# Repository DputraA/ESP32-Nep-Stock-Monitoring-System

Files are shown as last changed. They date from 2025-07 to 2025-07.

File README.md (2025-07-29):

# ESP32 Nepel Stock Monitoring System

Sistem monitoring persediaan nepel berbasis ESP32, multiplexer (MUX), dan web server lokal, dengan fitur pengiriman data ke Google Sheets dan tampilan real-time status melalui halaman web. Sistem ini digunakan untuk mendeteksi apakah stok nepel tersedia (`ready`) atau habis (`runout`), dan mencatat log perubahan status serta uptime WiFi ESP32.

---

## Fitur Utama

- Monitoring hingga 4 channel sensor digital (bisa diperluas)
- Deteksi perubahan status sensor secara otomatis
- Pengiriman data ke Google Spreadsheet via WebScript
- Webserver lokal dengan tampilan status dan log
- Fitur uptime monitoring (timer berjalan jika WiFi aktif)
- Auto-refresh dashboard jika ada perubahan
- Log maksimal 10 perubahan terakhir ditampilkan di halaman web
- Auto-reconnect jika WiFi terputus

---

## Struktur Proyek

File utama:
- `main.ino`= file kode utama ESP32
- `README.md`= dokumentasi ini
- 'Appscript for Spreadsheet.json' = Appscript penghubung ke spreadsheet
- 'Dashboard monitoring stock nepel.html' = Auto redirect ke halaman webserver
---

## Tampilan Webserver

Dashboard lokal menampilkan:
- Status semua channel (warna hijau = ready, merah = runout)
- Timestamp update terakhir setiap channel
- Log perubahan terakhir
- Uptime dari koneksi WiFi

---

##  Cara Upload dan Jalankan

1. Buka file `.ino` dengan Arduino IDE
2. Pastikan library berikut sudah tersedia:
   - `WiFi.h`
   - `WebServer.h`
   - `HTTPClient.h`
   - `ArduinoJson.h`
   - `time.h`
3. Atur:
   - `ssid` dan `password` sesuai WiFi lokal
   - `scriptURL` sesuai link Google Apps Script Anda
4. Upload ke ESP32
5. Buka file 'Dashboard monitoring stock nepel.html' di browser

---

## Menambah Channel Sensor

Secara default, sistem membaca 4 channel (`totalChannels = 4`). Untuk menambah jumlah channel:

1. Ubah variabel `totalChannels`:
  	 ```cpp
  	 const int totalChannels = 8;
2. Update array namaNepel[] agar mencakup semua channel baru:

 	  ```cpp
	const char* namaNepel[totalChannels] = {
	"Nepel 12-12", "Nepel 12-10", "Nepel 10-10", "Nepel Single 10",
	"Nepel Extra 1", "Nepel Extra 2", "Nepel Extra 3", "Nepel Extra 4"
	};
3. (Opsional) Aktifkan multiplexer kedua/ketiga jika total channel melebihi 8 atau 16:

	```cpp
	digitalWrite(muxEN1, LOW);  // Channel 0–7
	digitalWrite(muxEN2, LOW);  // Channel 8–15 (MUX 2)
	digitalWrite(muxEN3, LOW);  // Channel 16–23 (MUX 3)

## Mengganti Nama Channel
1. Edit isi array namaNepel[] sesuai urutan channel:

	```cpp
	const char* namaNepel[totalChannels] = {
	  "Nepel A", "Nepel B", "Nepel C", "Nepel D"
	};

2. Nama ini akan digunakan untuk:

- Label log di spreadsheet

- Tampilan web dashboard

- JSON yang dikirim ke Google Sheets

## Membuka Webserver Menggunakan redirect `.html`

Agar lebih mudah mengakses IP lokal ESP32 tanpa mengetik alamat IP manual, gunakan file Redirect `Dashboard monitoring stock nepel.html`.

## Catatan Tambahan
Tempat penyimpanan fisik saat ini hanya mampu menampung 4 jenis material nepel dan menggunakan impraboard.
Disarankan untuk mengganti tempat penyimpanan ke bahan stainless steel agar lebih kuat, awet, dan cocok digunakan di lingkungan pabrik.
Pastikan power supply memberikan tegangan 5V stabil ke ESP32, dan 24V untuk sensor serta pilot lamp.

![Dashboard](https://github.com/user-attachments/assets/8dd31693-6f9d-41be-ad02-e86e2364a81c)

## Lisensi
Proyek ini bersifat open-source dan bebas digunakan untuk edukasi dan pengembangan lebih lanjut.

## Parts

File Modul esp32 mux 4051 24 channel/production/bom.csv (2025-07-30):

Designator | Footprint | Quantity | Value | LCSC Part #
C1, C3 | CP_Elec_8x10 | 2 | 220uF
C2, C4 | 1206 | 2 | 100nF
D1, D2 | D_SMA_Handsoldering | 2 | SS14
D3 | 1206 | 1 | LED
J1, J2 | PinHeader_1x02_P2.54mm_Vertical | 2 | Conn_01x02_Socket
J10, J11, J12, J13, J14, J15, J16, J17, J18, J19, J20, J21, J22, J23, J24, J25, J26, J27, J4, J5, J6, J7, J8, J9 | JST_XH_B3B-XH-A_1x03_P2.50mm_Vertical | 24 | Conn_01x03_Pin
J3 | KF7.62_2P | 1 | Screw_Terminal_01x02
L1 | L_12x12mm_H8mm | 1 | 68uH
M1, M2, M3 | SOIC-16W_5.3x10.2mm_P1.27mm | 3 | 74HC4051
R1, R10, R11, R12, R13, R14, R15, R16, R17, R18, R19, R2, R20, R21, R22, R23, R24, R25, R26, R27, R28, R3, R5, R6, R7, R8, R9 | 1206 | 27 | R
R4 | 1206 | 1 | 1K
U1 | MODULE_ESP32-DEVKITC | 1 | ESP32-DEVKITC-v4
U10, U11, U12, U13, U14, U15, U16, U17, U18, U19, U20, U21, U22, U23, U24, U25, U26, U3, U4, U5, U6, U7, U8, U9 | DIP-4_W7.62mm_SMDSocket_SmallPads | 24 | PC817
U2 | TO-263-5_TabPin3 | 1 | LM2596S-5

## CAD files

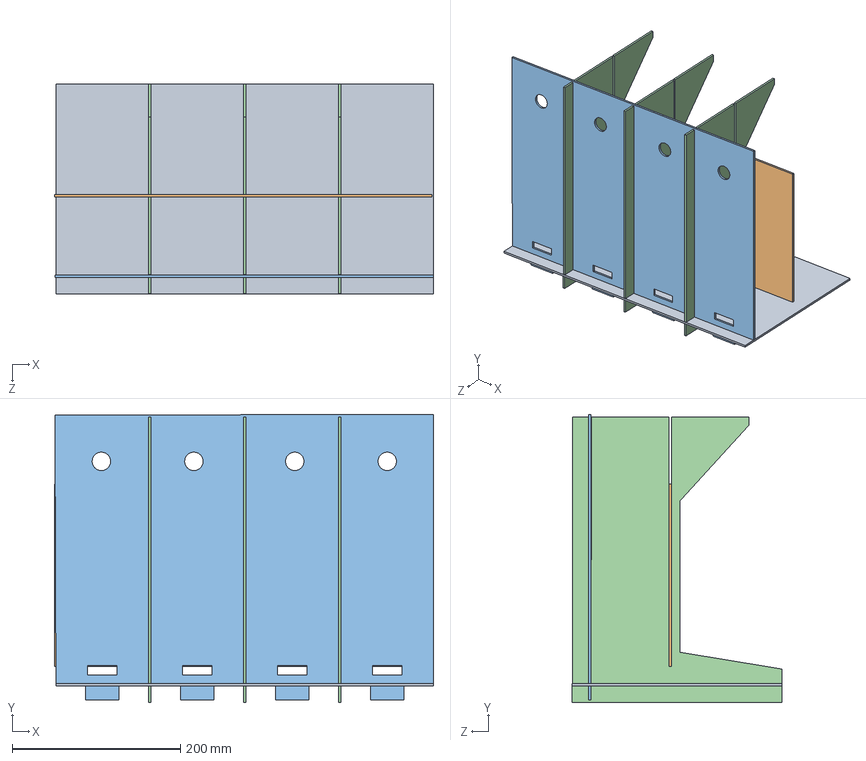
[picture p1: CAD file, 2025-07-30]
dispenser nepel/assy.SLDASM
450.7 x 343.0 x 250.0 mm
bawah
depan
dinding belakang
dinding pinggir x 3

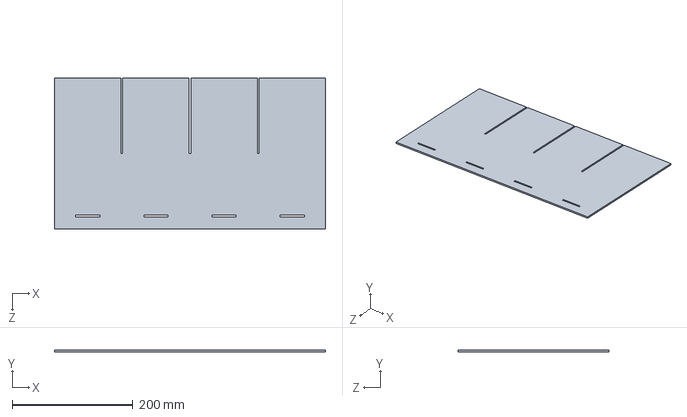
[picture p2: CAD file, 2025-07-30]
dispenser nepel/bawah.SLDPRT
449.0 x 3.00 x 250.0 mm

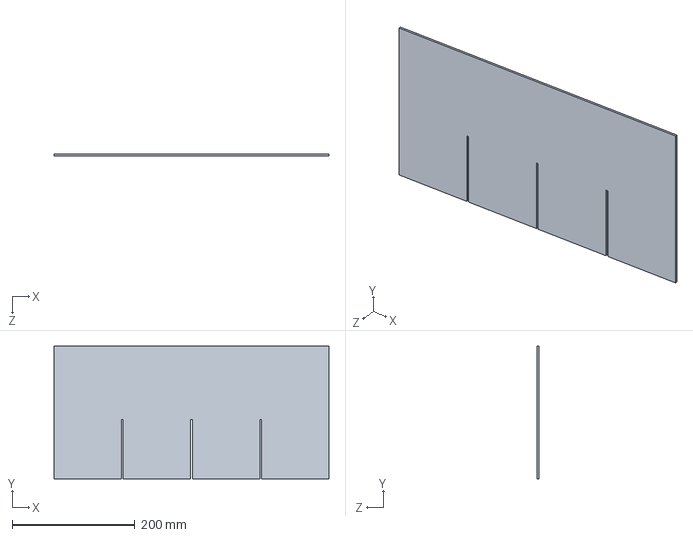
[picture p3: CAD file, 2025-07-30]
dispenser nepel/depan.SLDPRT
449.0 x 217.0 x 3.00 mm

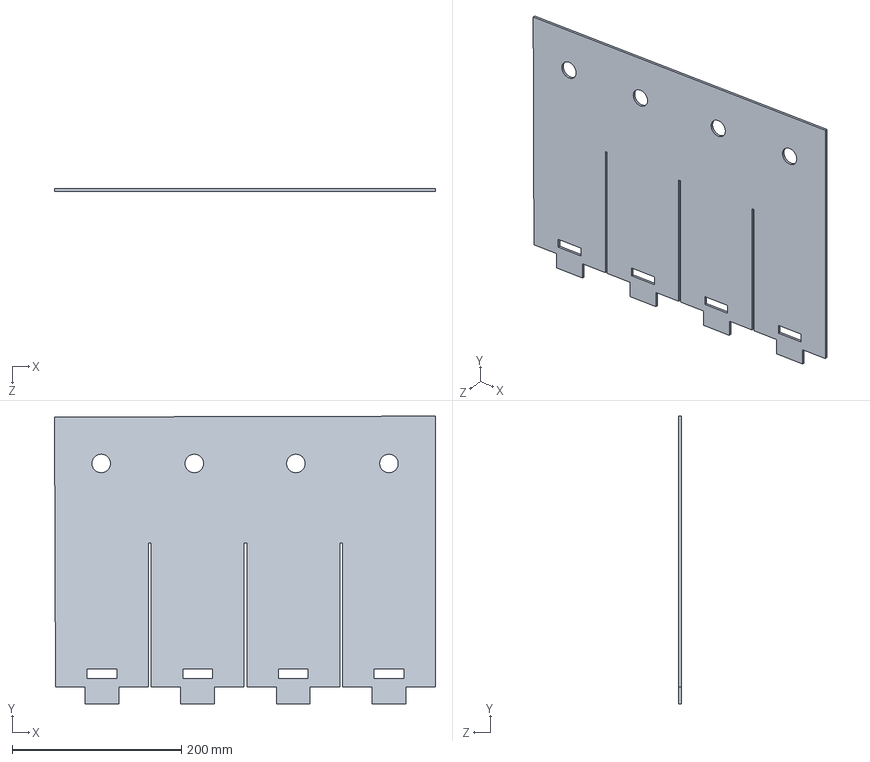
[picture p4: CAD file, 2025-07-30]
dispenser nepel/dinding belakang.SLDPRT
450.2 x 340.0 x 3.00 mm

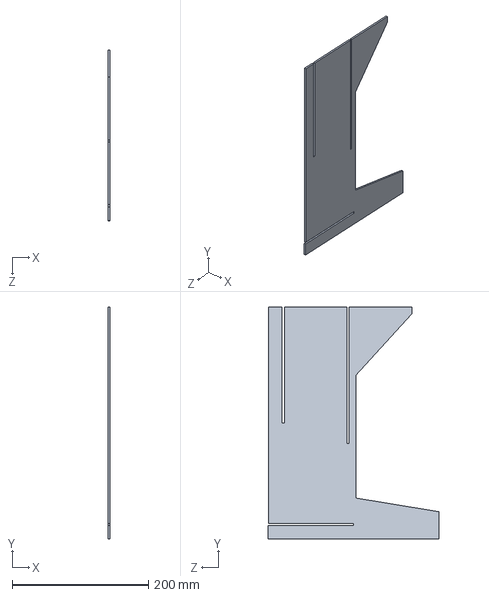
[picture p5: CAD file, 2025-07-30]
dispenser nepel/dinding pinggir.SLDPRT
3.00 x 340.0 x 250.0 mm

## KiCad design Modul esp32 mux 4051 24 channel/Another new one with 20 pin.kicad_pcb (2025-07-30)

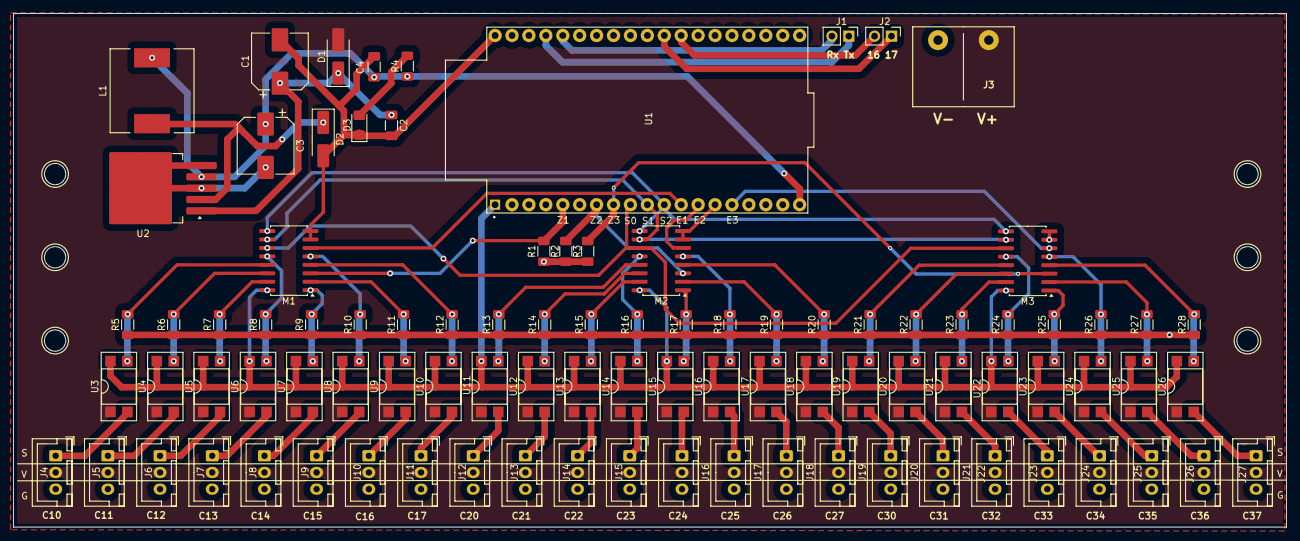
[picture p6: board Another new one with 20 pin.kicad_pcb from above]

Board: 2 copper layers, 191.1 x 77.1 mm, 92 parts (0 on the bottom side), 68 nets.

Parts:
C1, C3: 220uF; CP_Elec_8x10
C2, C4: 100nF; C_1206_3216Metric_Pad1.33x1.80mm_HandSolder
D1, D2: SS14; D_SMA_Handsoldering
D3: LED; LED_1206_3216Metric_Pad1.42x1.75mm_HandSolder
J1, J2: Conn_01x02_Socket; PinHeader_1x02_P2.54mm_Vertical
J3: Screw_Terminal_01x02; KF7.62_2P
J4, J5, J6, J7, J8, J9, J10, J11, J12, J13, J14, J15, J16, J17, J18, J19, J20, J21, J22, J23, J24, J25, J26, J27: Conn_01x03_Pin; JST_XH_B3B-XH-A_1x03_P2.50mm_Vertical
L1: 68uH; L_12x12mm_H8mm
M1, M2, M3: 74HC4051; SOIC-16W_5.3x10.2mm_P1.27mm
R1, R2, R3, R5, R6, R7, R8, R9, R10, R11, R12, R13, R14, R15, R16, R17, R18, R19, R20, R21, R22, R23, R24, R25, R26, R27, R28: R; R_1206_3216Metric_Pad1.30x1.75mm_HandSolder
R4: 1K; R_1206_3216Metric_Pad1.30x1.75mm_HandSolder
U1: ESP32-DEVKITC-v4; MODULE_ESP32-DEVKITC
U2: LM2596S-5; TO-263-5_TabPin3
U3, U4, U5, U6, U7, U8, U9, U10, U11, U12, U13, U14, U15, U16, U17, U18, U19, U20, U21, U22, U23, U24, U25, U26: PC817; DIP-4_W7.62mm_SMDSocket_SmallPads

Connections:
/Buck Converter 24 to 5/GND: C1.2, C2.2, C3.2, C4.2, D2.2 (A), D3.1 (K), J3.2, J4.3, J5.3, J6.3, J7.3, J8.3, J9.3, J10.3, J11.3, J12.3, J13.3, J14.3, J15.3, J16.3, J17.3, J18.3, J19.3, J20.3, J21.3, J22.3, J23.3, J24.3, J25.3, J26.3, J27.3, M1.7 (VEE), M1.8 (GND), M2.7 (VEE), M2.8 (GND), M3.7 (VEE), M3.8 (GND), R1.1, R2.1, R3.1, R5.1, R6.1, R7.1, R8.1, R9.1, R10.1, R11.1, R12.1, R13.1, R14.1, R15.1, R16.1, R17.1, R18.1, R19.1, R20.1, R21.1, R22.1, R23.1, R24.1, R25.1, R26.1, R27.1, R28.1, U1.14 (GND1), U1.32 (GND2), U1.38 (GND3), U2.3 (GND), U2.5 (~ON/OFF)
/Buck Converter 24 to 5/IN: D1.2 (A), J3.1, J4.2, J5.2, J6.2, J7.2, J8.2, J9.2, J10.2, J11.2, J12.2, J13.2, J14.2, J15.2, J16.2, J17.2, J18.2, J19.2, J20.2, J21.2, J22.2, J23.2, J24.2, J25.2, J26.2, J27.2, U3.1, U4.1, U5.1, U6.1, U7.1, U8.1, U9.1, U10.1, U11.1, U12.1, U13.1, U14.1, U15.1, U16.1, U17.1, U18.1, U19.1, U20.1, U21.1, U22.1, U23.1, U24.1, U25.1, U26.1
/Buck Converter 24 to 5/OUT (5V): C3.1, C4.1, L1.2, R4.1, U1.19 (EXT_5V), U2.4 (FB)
/Multiplexer/1: J4.1, U3.2
/Multiplexer/2: J5.1, U4.2
/Multiplexer/3: J6.1, U5.2
/Multiplexer/3.3v: M1.16 (VCC), M2.16 (VCC), M3.16 (VCC), U1.1 (3V3), U3.4, U4.4, U5.4, U6.4, U7.4, U8.4, U9.4, U10.4, U11.4, U12.4, U13.4, U14.4, U15.4, U16.4, U17.4, U18.4, U19.4, U20.4, U21.4, U22.4, U23.4, U24.4, U25.4, U26.4
/Multiplexer/4: J7.1, U6.2
/Multiplexer/5: J8.1, U7.2
/Multiplexer/6: J9.1, U8.2
/Multiplexer/7: J10.1, U9.2
/Multiplexer/8: J11.1, U10.2
/Multiplexer/9: J12.1, U11.2
/Multiplexer/10: J13.1, U12.2
/Multiplexer/11: J14.1, U13.2
/Multiplexer/12: J15.1, U14.2
/Multiplexer/13: J16.1, U15.2
/Multiplexer/14: J17.1, U16.2
/Multiplexer/15: J18.1, U17.2
/Multiplexer/16: J19.1, U18.2
/Multiplexer/17: J20.1, U19.2
/Multiplexer/18: J21.1, U20.2
/Multiplexer/19: J22.1, U21.2
/Multiplexer/20: J23.1, U22.2
/Multiplexer/21: J24.1, U23.2
/Multiplexer/22: J25.1, U24.2
/Multiplexer/23: J26.1, U25.2
/Multiplexer/24: J27.1, U26.2
/Multiplexer/En1: M1.6 (~E), U1.12 (IO14)
/Multiplexer/En2: M2.6 (~E), U1.13 (IO12)
/Multiplexer/En3: M3.6 (~E), U1.15 (IO13)
/Multiplexer/Out1: M1.3 (A), R1.2, U1.5 (IO34)
/Multiplexer/Out2: M2.3 (A), R2.2, U1.7 (IO32)
/Multiplexer/Out3: M3.3 (A), R3.2, U1.8 (IO33)
/Multiplexer/S0: M1.11 (S0), M2.11 (S0), M3.11 (S0), U1.9 (IO25)
/Multiplexer/S1: M1.10 (S1), M2.10 (S1), M3.10 (S1), U1.10 (IO26)
/Multiplexer/S2: M1.9 (S2), M2.9 (S2), M3.9 (S2), U1.11 (IO27)
unnamed: C1.1, C2.1, D1.1 (K), U2.1 (VIN)
unnamed: D2.1 (K), L1.1, U2.2 (OUT)
unnamed: D3.2 (A), R4.2
unnamed: J1.1, U1.35 (TXD0)
unnamed: J1.2, U1.34 (RXD0)
unnamed: J2.1, U1.28 (IO17)
unnamed: J2.2, U1.27 (IO16)
unnamed: M1.13 (A0), R5.2, U3.3
unnamed: M1.14 (A1), R6.2, U4.3
unnamed: M1.15 (A2), R7.2, U5.3
unnamed: M1.12 (A3), R8.2, U6.3
unnamed: M1.1 (A4), R9.2, U7.3
unnamed: M1.5 (A5), R10.2, U8.3
unnamed: M1.2 (A6), R11.2, U9.3
unnamed: M1.4 (A7), R12.2, U10.3
unnamed: M2.13 (A0), R13.2, U11.3
unnamed: M2.14 (A1), R14.2, U12.3
unnamed: M2.15 (A2), R15.2, U13.3
unnamed: M2.12 (A3), R16.2, U14.3
unnamed: M2.1 (A4), R17.2, U15.3
unnamed: M2.5 (A5), R18.2, U16.3
unnamed: M2.2 (A6), R19.2, U17.3
unnamed: M2.4 (A7), R20.2, U18.3
unnamed: M3.13 (A0), R21.2, U19.3
unnamed: M3.14 (A1), R22.2, U20.3
unnamed: M3.15 (A2), R23.2, U21.3
unnamed: M3.12 (A3), R24.2, U22.3
unnamed: M3.1 (A4), R25.2, U23.3
unnamed: M3.5 (A5), R26.2, U24.3
unnamed: M3.2 (A6), R27.2, U25.3
unnamed: M3.4 (A7), R28.2, U26.3

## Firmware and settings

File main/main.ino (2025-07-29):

#include <WiFi.h>
#include <WebServer.h>
#include <HTTPClient.h>
#include <ArduinoJson.h>
#include <time.h>

const char* ssid = "OJI"; //SSID WIFI yang digunakan
const char* password = "OnejectOJI88!"; //Passsword WIFI 
const char* scriptURL = "https://script.google.com/macros/s/AKfycbwVFrP5pP18-7c_LFjP_pqilvWdEAkJ4rLQRrOwwP4Hp_kgN0dRqTads4bqfNdSx2onWA/exec";

const int muxS0 = 18;
const int muxS1 = 26;
const int muxS2 = 27;

const int muxEN1 = 14;
const int muxEN2 = 12;
const int muxEN3 = 13;

const int muxSIG = 34;
const int totalChannels = 4; //Jumlah jenis nepel yang dideteksi

WebServer server(80);

int lastSensorValues[totalChannels];
unsigned long falseStartTimes[totalChannels];
unsigned long lastCheckTime = 0;
const unsigned long checkInterval = 1000;

const char* namaNepel[totalChannels] = {"Nepel 12-12", "Nepel 12-10", "Nepel 10-10", "Nepel Single 10"}; //Daftar nama nepel yang dideteksi (diurutkan dari channel pertama)
String logs[10];
int logIndex = 0;

bool internetStatus = false;
bool googleSheetStatus = false;
int googleSheetCode = -1;
String googleSheetMessage = "Not Sent";

bool statusChanged = false;
bool wifiReconnected = false;

String lastUpdateTimestamps[totalChannels];

unsigned long lastWifiCheckTime = 0;
unsigned long wifiConnectedTime = 0;

void setup() {
  Serial.begin(115200);
  pinMode(muxS0, OUTPUT);
  pinMode(muxS1, OUTPUT);
  pinMode(muxS2, OUTPUT);

  pinMode(muxEN1, OUTPUT);
  digitalWrite(muxEN1, LOW);
  digitalWrite(muxEN2, HIGH);
  digitalWrite(muxEN3, HIGH);
  pinMode(muxSIG, INPUT);

  connectToWiFi();

  configTime(0, 0, "pool.ntp.org", "time.nist.gov");
  waitForNTP();
  
  for (int ch = 0; ch < totalChannels; ch++) {
    lastSensorValues[ch] = readMUX(ch);
    lastUpdateTimestamps[ch] = getLocalTimeString();
  }

  server.on("/", handleRoot);
  server.on("/changed", []() {
    if (statusChanged || wifiReconnected) {
      statusChanged = false;
      wifiReconnected = false;
      server.send(200, "text/plain", "changed");
    } else {
      server.send(200, "text/plain", "nochange");
    }
  });
  server.begin();
}

void loop() {
  server.handleClient();
  if (millis() - lastWifiCheckTime >= 10000) {
    lastWifiCheckTime = millis();
    if (WiFi.status() != WL_CONNECTED) {
      Serial.println("WiFi Disconnected! Attempting reconnect...");
      connectToWiFi();
      if (WiFi.status() == WL_CONNECTED) {
        wifiReconnected = true;
        Serial.println("WiFi Reconnected!");
      }
    }
  }

  internetStatus = isInternetConnected();
  if (millis() - lastCheckTime >= checkInterval) {
    lastCheckTime = millis();
    for (int ch = 0; ch < totalChannels; ch++) {
      int currentValue = readMUX(ch);
      if (currentValue != lastSensorValues[ch]) {
        statusChanged = true;
        String nama = namaNepel[ch];
        String status = currentValue == 1 ? "runout" : "ready";
        unsigned long duration = 0;
        if (currentValue == 0) falseStartTimes[ch] = millis();
        else if (lastSensorValues[ch] == 0)
          duration = millis() - falseStartTimes[ch];

        lastSensorValues[ch] = currentValue;
        lastUpdateTimestamps[ch] = getLocalTimeString();
        sendStatusToGoogleSheet(nama, status);

        String logEntry = getLocalTimeString() + " - " + nama + " menjadi " + status;
        logs[logIndex % 10] = logEntry;
        logIndex++;
      }
    }
  }
}

void connectToWiFi() {
  WiFi.begin(ssid, password);
  Serial.print("Connecting to WiFi");
  unsigned long startAttemptTime = millis();
  while (WiFi.status() != WL_CONNECTED && millis() - startAttemptTime < 10000) {
    Serial.print(".");
    delay(500);
  }
  if (WiFi.status() == WL_CONNECTED) {
    Serial.println("\\nWiFi Connected: " + WiFi.localIP().toString());
    sendIPToGoogleSheet(WiFi.localIP().toString());
    wifiConnectedTime = millis();
  } else {
    Serial.println("\\nWiFi Connection Failed.");
  }
}

int readMUX(int channel) {
  digitalWrite(muxS0, bitRead(channel, 0));
  digitalWrite(muxS1, bitRead(channel, 1));
  digitalWrite(muxS2, bitRead(channel, 2));
  delay(20);
  return digitalRead(muxSIG);
}

void waitForNTP() {
  Serial.print("Waiting for NTP time sync");
  time_t now = time(nullptr);
  int attempts = 0;

  while (now < 8 * 3600 * 2 && attempts < 20) { // tunggu hingga waktu valid (lebih dari 1970)
    delay(500);
    Serial.print(".");
    now = time(nullptr);
    attempts++;
  }

  if (now >= 8 * 3600 * 2) {
    Serial.println("\nNTP time synchronized.");
  } else {
    Serial.println("\nNTP sync failed, using fallback time.");
  }
}

void handleRoot() {
  bool isTimestampValid = true;
  for (int i = 0; i < totalChannels; i++) {
    if (lastUpdateTimestamps[i].startsWith("1970")) {
      isTimestampValid = false;
      break;
    }
  }

  String html = "<!DOCTYPE html><html lang='en'><head><meta charset='UTF-8' />";
  html += "<meta name='viewport' content='width=device-width, initial-scale=1.0' />";
  if (!isTimestampValid) {
    html += "<meta http-equiv='refresh' content='2'>";  // Tambahkan ini jika timestamp belum valid
  }
  html += "<title>DASHBOARD MONITORING STOCK NEPEL</title>";
  html += "<style>body{margin:0;font-family:Arial,sans-serif;background:#f8f8f8}";
  html += "header{background-color:#4b9cdb;color:white;padding:20px 40px;box-shadow:0 2px 5px rgba(0,0,0,0.1)}";
  html += "header h1{margin:0;font-size:28px;font-weight:bold;text-shadow:2px 2px 0px #2c72a8}";
  html += "header h2{margin:5px 0 0 0;font-size:16px;font-weight:600}";
  html += ".container{display:flex;flex-wrap:wrap;gap:30px;padding:20px 40px}";
  html += ".status-section{flex:1 1 400px;max-width:700px}";
  html += ".log-section{flex:1 1 300px;max-width:600px}";
  html += ".status-section h3{text-align:center;margin-bottom:15px}";
  html += ".status-cards{display:flex;gap:15px;flex-wrap:wrap;justify-content:center;background:white;padding:20px;border-radius:20px;box-shadow:6px 6px 0px #aaa}";
  html += ".card{color:white;padding:15px;border-radius:20px;width:120px;text-align:center;font-weight:bold}";
  html += ".ready{background:#2b7a1f;}.runout{background:#c0392b;}.card small{display:block;font-weight:normal;font-size:12px;margin-top:5px}";
  html += ".uptime-box{margin-top:20px;background:white;padding:20px;border-radius:20px;text-align:center;box-shadow:4px 4px 8px rgba(0,0,0,0.1)}";
  html += ".uptime-box .uptime-title{font-size:16px;font-weight:bold;margin-bottom:8px;color:#444}";
  html += ".uptime-box #uptime{font-size:20px;color:#2b7a1f;font-weight:bold}";
  html += ".log-table{background:white;border-radius:20px;overflow:hidden;box-shadow:3px 3px 10px rgba(0,0,0,0.1)}";
  html += ".log-header{background:#4b9cdb;color:white;padding:10px;font-weight:bold;display:flex;justify-content:space-between;text-align:center}";
  html += ".log-header div{flex:1;padding:10px;text-align:center;min-width:0;box-sizing:border-box}";
  html += ".log-body{padding:10px 0;font-size:14px}.log-row{display:flex;justify-content:space-between;margin-bottom:5px}";
  html += ".log-row div{flex:1;padding:10px;text-align:center;min-width:0;box-sizing:border-box}";
  html += "@media screen and (max-width: 767px){.container{flex-direction:column;padding:10px}.status-section,.log-section{max-width:100%;padding:0}";
  html += ".status-cards{flex-direction:column;align-items:center}.card{width:80%}.uptime-box{margin-top:20px}}";
  html += ".log-link{text-align:center;margin-top:15px}";
  html += ".log-button{display:inline-block;background:#4b9cdb;color:white;padding:12px 24px;border-radius:10px;font-weight:bold;font-size:16px;text-decoration:none;box-shadow:2px 2px 6px rgba(0,0,0,0.2);transition:0.2s ease-in-out}";
  html += ".log-button:hover{background:#357ab8;transform:translateY(-2px);cursor:pointer}";
  html += "</style></head><body>";
  html += "<header><h1>DASHBOARD MONITORING STOCK NEPEL</h1><h2>INJECTION MOLDING</h2></header>";
  html += "<div class='container'><div class='status-section'><h3>STATUS</h3><div class='status-cards'>";

  for (int ch = 0; ch < totalChannels; ch++) {
    int value = lastSensorValues[ch];
    String name = String(namaNepel[ch]);
    String statusClass = value == 1 ? "runout" : "ready";
    String timestamp = lastUpdateTimestamps[ch];
    String dateStr = timestamp.substring(0, 10);
    String timeStr = timestamp.substring(11);

    html += "<div class='card " + statusClass + "'>" + name;
    html += "<small>Date: " + dateStr.substring(8,10) + "/" + dateStr.substring(5,7) + "/" + dateStr.substring(0,4) + "</small>";
    html += "<small>Time: " + timeStr + "</small></div>";
  }

  html += "</div>"; // end .status-cards

  // Tambahkan kotak uptime di bawah status-cards
  html += "<div class='uptime-box'>";
  html += "<div class='uptime-title'>UPTIME</div>";
  html += "<div id='uptime'>" + getUptimeString() + "</div>";
  html += "</div>"; // end .uptime-box

  // Tombol link ke spreadsheet
  html += "<div class='log-link'>";
  html += "<a href='https://docs.google.com/spreadsheets/d/1QFN6b2QaQEETtJYHuudSkTxjHCEVqrDJlAq6RTz8lxI/edit?usp=sharing' target='_blank'>";
  html += "<div class='log-button'>&#10148; Full Logs</div></a></div>";

  html += "</div><div class='log-section'><div class='log-table'>";
  html += "<div class='log-header'><div>TIMESTAMP</div><div>NAME</div><div>STATUS</div></div><div class='log-body'>";

  int displayCount = min(logIndex, 10);

  for (int i = 0; i < displayCount; i++) {
    int index = (logIndex - 1 - i + 10) % 10;
    String log = logs[index];
    int sep1 = log.indexOf(" - ");
    int sep2 = log.indexOf(" menjadi ");
    String timestamp = log.substring(0, sep1);
    String name = log.substring(sep1 + 3, sep2).substring(6);
    String stat = log.substring(sep2 + 9);
    stat.replace("runout", "Runout");
    stat.replace("ready", "Ready");

    html += "<div class='log-row'><div>" + timestamp + "</div><div>" + name + "</div><div>" + stat + "</div></div>";
  }

  html += "</div></div></div></div>";
  html += "<script>";
  html += "setInterval(() => { fetch('/changed').then(res => res.text()).then(data => { if(data === 'changed'){ location.reload(); }}); }, 2000);";
  html += "setInterval(() => { const el = document.getElementById('uptime'); if(el){ let parts = el.textContent.split(':').map(Number); let h=parts[0],m=parts[1],s=parts[2]; s++; if(s>=60){s=0;m++;} if(m>=60){m=0;h++;} el.textContent=`${String(h).padStart(2,'0')}:${String(m).padStart(2,'0')}:${String(s).padStart(2,'0')}`; } }, 1000);";
  html += "</script></body></html>";

  server.send(200, "text/html", html);
}

void sendIPToGoogleSheet(String ip) {
  HTTPClient http;
  String encodedIP = "'" + ip;
  String url = String(scriptURL) + "?ip=" + encodedIP;
  Serial.println("Sending to: " + url);
  http.begin(url);
  int code = http.GET();
  Serial.println("Response code: " + String(code));
  http.end();
}

void sendStatusToGoogleSheet(String nama, String status) {
  HTTPClient http;
  String encodedNama = urlEncode(nama);
  String encodedStatus = urlEncode(status);
  String url = String(scriptURL) + "?nama=" + encodedNama + "&status=" + encodedStatus;
  http.begin(url);
  int httpCode = http.GET();
  googleSheetCode = httpCode;
  googleSheetStatus = (httpCode > 0 && httpCode < 400);
  googleSheetMessage = httpCode > 0 ? "OK" : "Error: " + String(http.errorToString(httpCode));
  http.end();
}

String getLocalTimeString() {
  time_t rawtime = time(nullptr) + 7 * 3600;
  struct tm* timeinfo = gmtime(&rawtime);
  char buffer[30];
  strftime(buffer, sizeof(buffer), "%Y-%m-%d %H:%M:%S", timeinfo);
  return String(buffer);
}

String getUptimeString() {
  unsigned long seconds = (millis() - wifiConnectedTime) / 1000;
  unsigned int h = seconds / 3600;
  unsigned int m = (seconds % 3600) / 60;
  unsigned int s = seconds % 60;
  char buffer[10];
  sprintf(buffer, "%02u:%02u:%02u", h, m, s);
  return String(buffer);
}


bool isInternetConnected() {
  WiFiClient testClient;
  return testClient.connect("google.com", 80);
}

String urlEncode(const String& str) {
  String encoded = "";
  char c;
  char code[4];
  for (int i = 0; i < str.length(); i++) {
    c = str.charAt(i);
    if (isalnum(c)) {
      encoded += c;
    } else {
      sprintf(code, "%%%02X", c);
      encoded += code;
    }
  }
  return encoded;
}
